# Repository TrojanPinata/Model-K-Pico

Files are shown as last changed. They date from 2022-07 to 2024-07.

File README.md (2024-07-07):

# Model K Pico
This is the repository for a custom 75% keyboard designed to be a fusion of the [Cannonkeys Satisfaction75](https://cannonkeys.com/products/gb-satisfaction-75-keyboard-round-2), [CFTKB Mysterium](https://github.com/coseyfannitutti/mysterium), and [Envious Data Delirium](https://github.com/Envious-Data/Env-KB). I've designed around the ATmega32A and similar AVR controllers, and I really wanted to try working with the RP2040 as it comes fully prepackaged and works with [KMK](https://github.com/KMKfw/kmk_firmware) or  [QMK](https://github.com/qmk/qmk_firmware/tree/develop) (with the develop branch *kinda*). The original things that led me to do this were my desire to have the 75% form factor, exposed PCB, rotary encoder for audio, and I2C OLED display all in the same package. My goal was to combine all of these things together while still keeping it reasonable for a layman to make themself. 

I think it has come out pretty decent minus some cracks in the switchplate (because 1.5mm acrylic is really thin) and a misplaced screw hole. I couldnt find M2 screws short notice either so I ended up drilling out the holes to be larger (which was a mistake and I would not do again). I think it looks good, it sounds good, and most of all it works. The only thing I need is some pads to keep  it from slipping :).

If you plan on making this yourself I will try and make a guide in the future, but that might take a bit. I recommend [Ponoko](https://www.ponoko.com/) for the acrylic and [JLCPCB](https://jlcpcb.com/) for the PCB manufacturing. Everything else can be found in the BOM from either your local hardware store, [Keeb.io](https://keeb.io/) or [Divinikey](https://divinikey.com/). I chose to use some cheap keycaps and Gateron KS-9 2.0 Red switches and I like how everything feels. Anyway, if you have any questions start a issue or something B).

Note 07/07/24: I still daily drive this keyboard and something I think I should mention if you plan to use KMK daily is that the CircuitPython drive will inevitably corrupt. It lasted me a good two years before it started to get weird and then I basically could not mount the drive. It’s not a big deal if it works (and honestly, I only noticed it was bad when I went to reference some code). I switched to QMK recently and it has been so much better. The build I used is based on one of my future projects and works wonders.

final build

top down

rear

pcb but 3d

pcb 3d back

pcb in kicad

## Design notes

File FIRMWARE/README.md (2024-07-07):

# Firmware
~~I used KMK for this project because python is easy. I *plan* to eventually switch over to QMK less for the advanced features and more for the cleanliness of it. I don't think I'll do it soon becuase of the way the RP2040 isn't fully supported. In the meantime, pretty much everything that can be done in QMK can be done in KMK. With exception to turning off the OLED display it seems.~~

Switched to QMK and it is quite literally a equivalent to better experience. I put the keymap and uf2 here incase someone needs to flash their board.

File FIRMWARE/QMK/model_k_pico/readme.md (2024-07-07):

# Model-B

A 75% keyboard based on the RP2040.

* Keyboard Maintainer: [Brian Hill](https://github.com/TrojanPinata)
* Hardware Supported: [GitHub](https://github.com/TrojanPinata/Model-B)

## Revisions

At the current moment there is only one variant of the Model-B, the rev-0 (aka the prototype board). Any others are clones and may not have the exact firmware requirements.

## Building and Flashing

Make example for this keyboard (after setting up your build environment):

    make trojan_pinata/model-b/rev0:default
    
Flashing example for this keyboard:

    make trojan_pinata/model-b/rev0:default:flash

Compile example:

    qmk compile -kb trojan_pinata/model_b/rev0 -km default

See the [build environment setup](https://docs.qmk.fm/#/getting_started_build_tools) and the [make instructions](https://docs.qmk.fm/#/getting_started_make_guide) for more information. Brand new to QMK? Start with our [Complete Newbs Guide](https://docs.qmk.fm/#/newbs).

## Bootloader

Enter the bootloader in 3 ways:

* **Bootmagic reset**: Hold down the top left key and plug in the keyboard. This will also clear the emulated EEPROM, so it is a good first step if the keyboard is misbehaving.
* **Physical reset button**: Hold down the `BOOTSEL` button on the Pi Pico, then either plug the board in or press the `RESET` button.
* **Keycode in layout**: Press the key mapped to `QK_BOOT`. In the pre-supplied keymaps it is on the second layer, replacing the Esc key.

After entering the bootloader through one of the three methods above, the keyboard will appear as a USB mass storage device named `RPI-RP2`. If the CLI is unable to find this device, the compiled `.uf2` file can be manually copied to it. The keyboard will reboot on completion with the new firmware loaded.

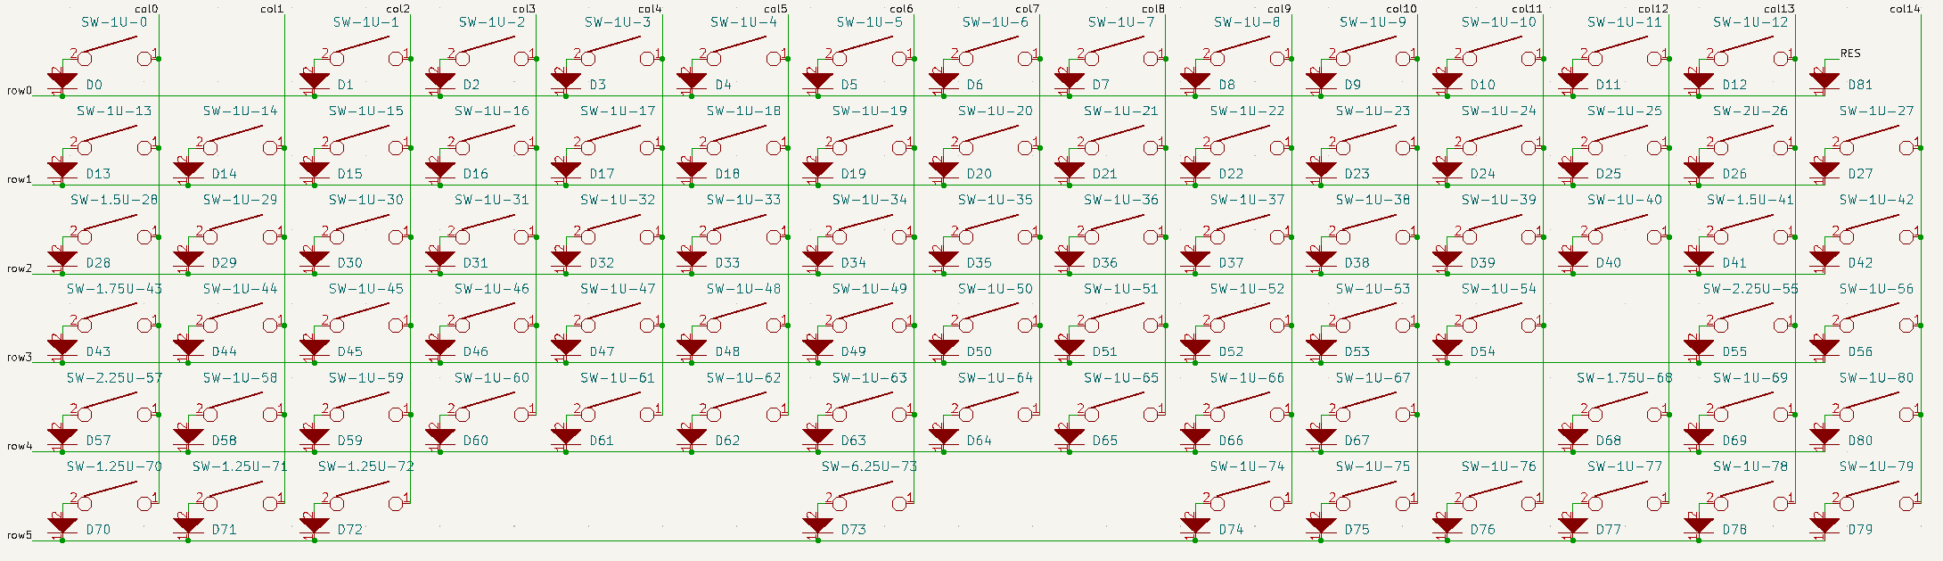
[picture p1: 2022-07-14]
DOCS/IMAGES/Schematic2.png

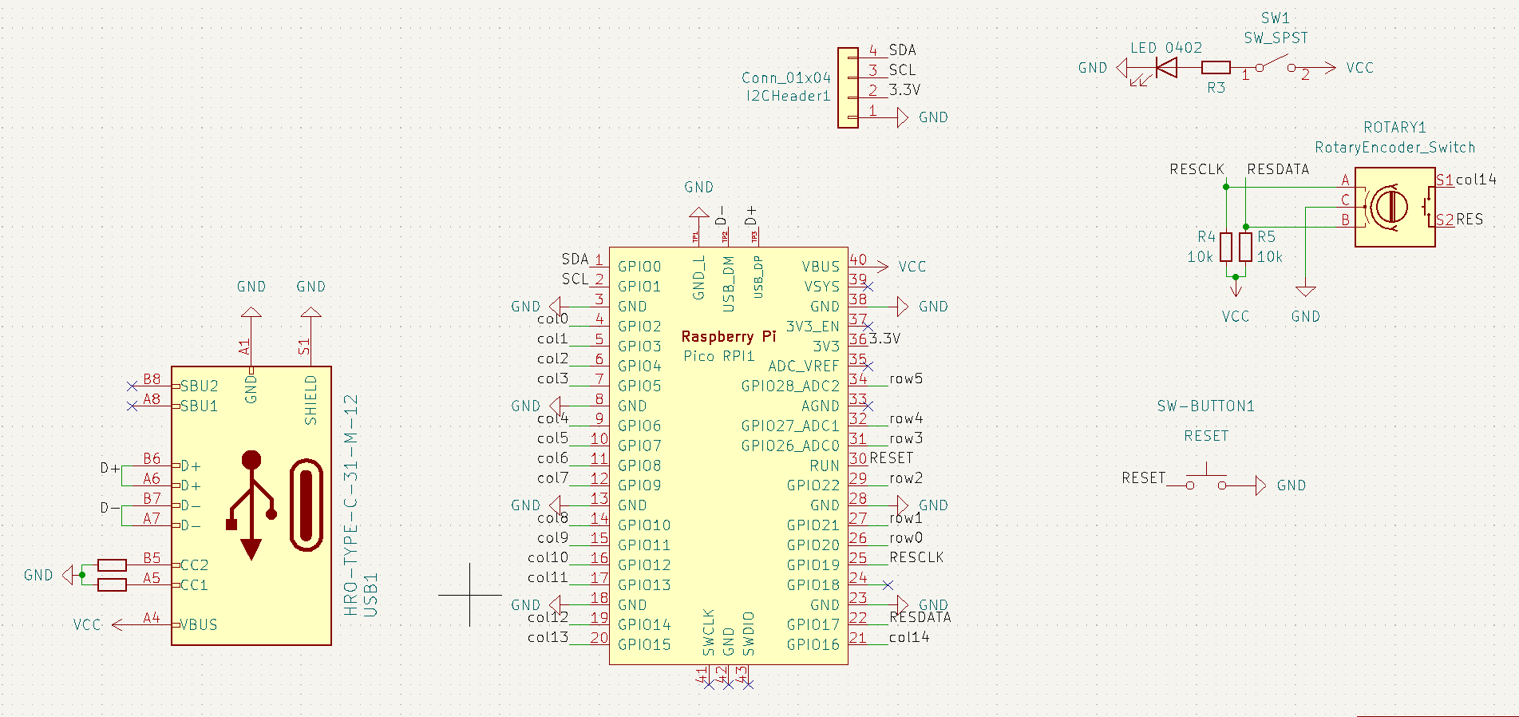
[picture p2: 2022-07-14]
DOCS/IMAGES/Schematic1.png

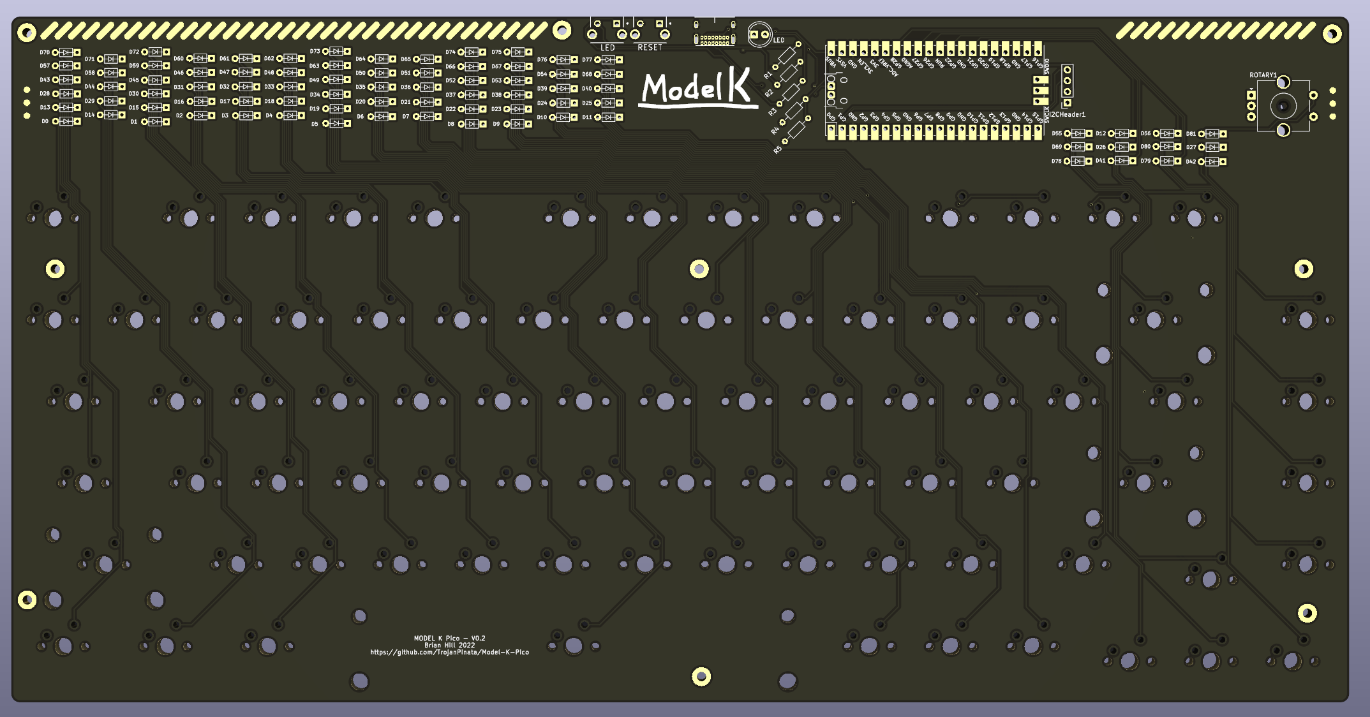
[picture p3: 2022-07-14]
DOCS/IMAGES/PCB2.png

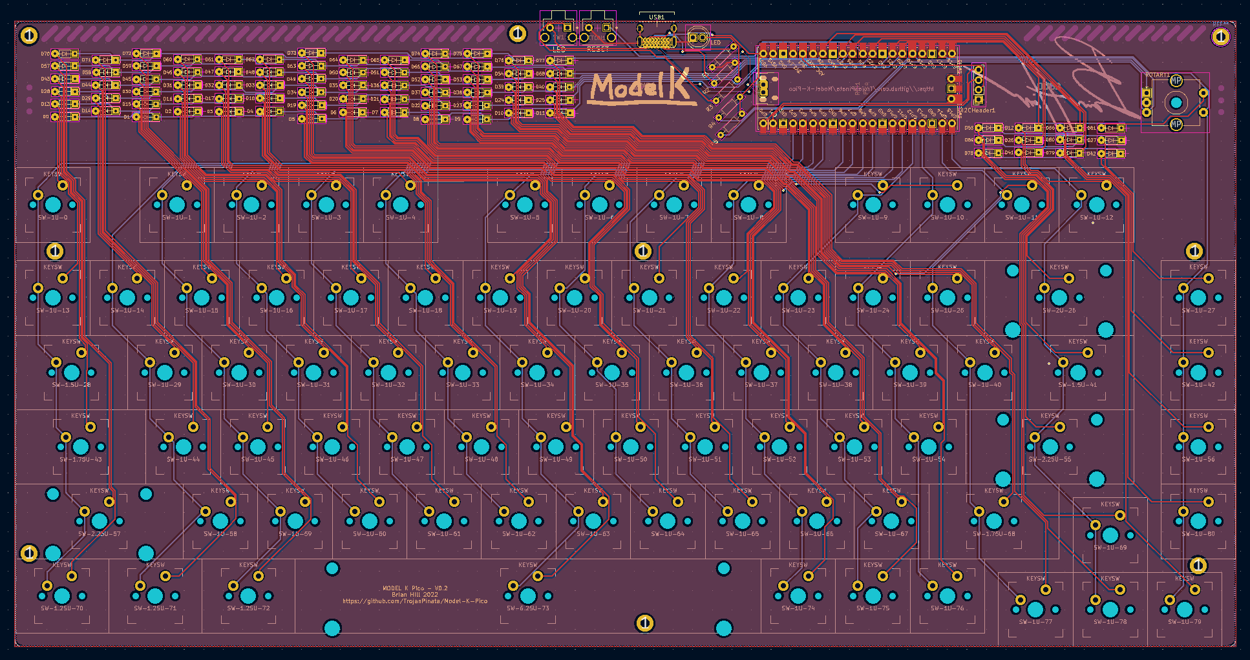
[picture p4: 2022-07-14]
DOCS/IMAGES/PCB1.png

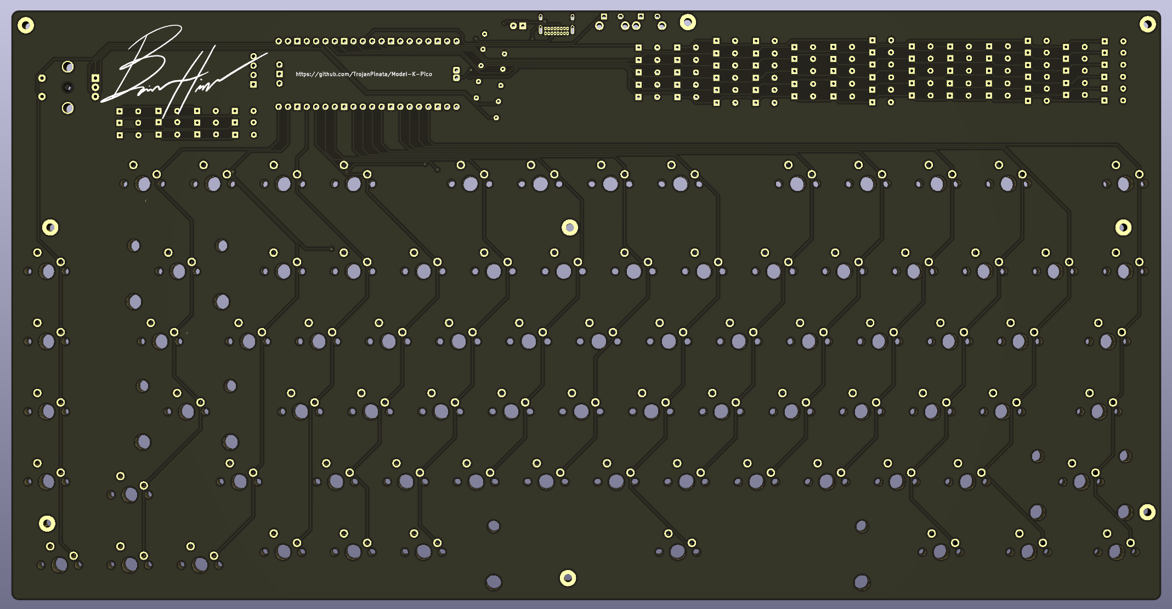
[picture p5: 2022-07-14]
DOCS/IMAGES/PCB3.png

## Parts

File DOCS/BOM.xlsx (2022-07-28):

Item | Description | Count | Notes | Link
Acrylic Switchplate | switchplate | 1
Acrylic Backplate | backplate | 1
Main PCB | pcb | 1
10k Resistor | encoder resistor | 2 | the ebay item to the left is just a general pack for a bunch of different types. they're cheap so you might as well get one so you don't need to order any in the future | https://www.ebay.com/itm/293925230123
5.1k Resistor | USB-C resistor | 2
47k Resistor | LED resistor | 1
SSD1306 | OLED display | 1 | get a second as a backup
EC11 | rotary encoder | 1 | get 2 for peace of mind | https://keeb.io/collections/diy-parts/products/rotary-encoder-ec11
encoder knob | knob for encoder…............... unless for some reason you don't want one i guess | 1 | I like the gmmk pro knob | https://keeb.io/collections/diy-parts/products/rotary-encoder-knob-ec11
1N4148 Diodes | switch diodes | 82 |  | https://keeb.io/collections/diy-parts/products/1n4148-diodes
Omron B3F 3XXX | Horizontal Button | 2 | pretty much anything of similar shape will work. I like the ones from keeb.io | https://www.digikey.com/en/products/detail/omron-electronics-inc-emc-div/B3F-3122/90406
Cherry Style Switches | keyb switches | 81 |  | https://divinikey.com/products/gateron-ks-9-pro-2-0-switches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
Keycaps | keybcaps | 1 | black pcb because color matching to green is hard
M2 Screws 10mm /Nuts | screws/nuts | 18 | 9 screws 18 nuts. I live in the US so #4-40 1/2in also work but you need to drill the holes larger | https://www.homedepot.com/p/Everbilt-M3-0-5-x-10-mm-Phillips-Pan-Head-Zinc-Plated-Machine-Screw-3-Pack-802708/204282658
4x1 Female Header | OLED header | 1 |  | https://www.ebay.com/itm/293487640349
20x1 Female Header | Pico header | 2 |  | https://www.ebay.com/itm/294007298331
USB4085-GF-A | USB-C header | 1 |  | https://www.digikey.com/en/products/detail/gct/USB4085-GF-A/9859662
Raspberry Pi Pico | Microcontroller | 1 |  | https://www.digikey.com/en/products/detail/raspberry-pi/SC0915/13624793
5mm LED | LED | 1 | idk where to buy leds i bought them once like 5 years ago and i still have a ton | https://www.ebay.com/itm/391368927437
2U Stabilizers | PCB mount stabs | 3 |  | https://divinikey.com/collections/keyboard-stabilizers/products/durock-v2-stabilizers-screw-in
6.25U Stabilizer | PCB mount space bar stab | 1
Cable | very nice cable | 1 | not necessary, but you just built a keyboard, so buy yourself something nice | https://www.gloriousgaming.com/products/glorious-coil-cable-crimson-red

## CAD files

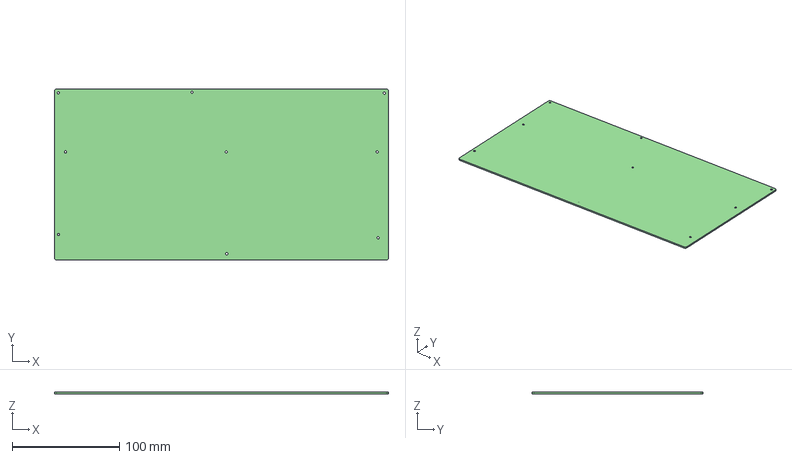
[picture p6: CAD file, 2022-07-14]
ACRYLIC-BOTTOM/ACRYLIC-BOTTOM.step
312.1 x 160.0 x 1.60 mm

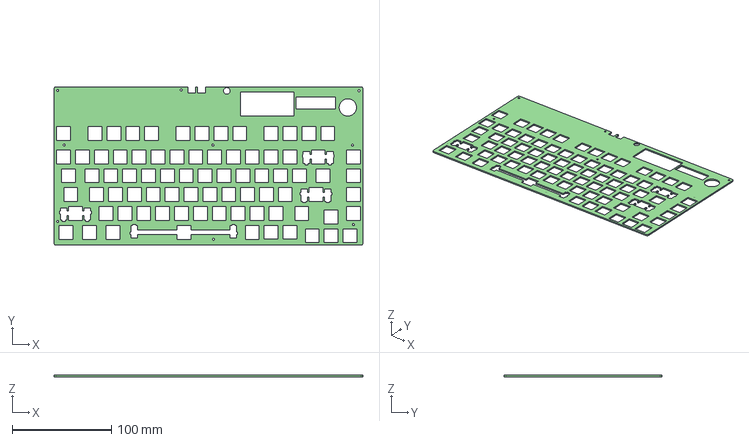
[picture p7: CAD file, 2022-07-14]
ACRYLIC-SP/ACRYLIC-TOP.step
312.1 x 160.0 x 1.60 mm

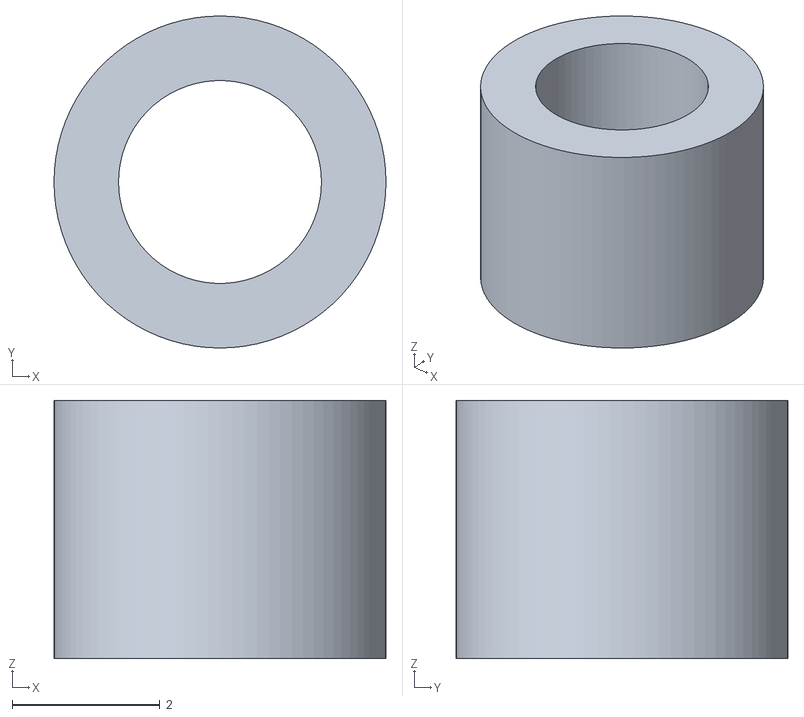
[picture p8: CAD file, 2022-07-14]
DOCS/spacer.stl
4.50 x 4.50 x 3.50

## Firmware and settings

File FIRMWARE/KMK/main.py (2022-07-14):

import board

from kb import KMKKeyboard
from kmk.keys import KC
from kmk.extensions.media_keys import MediaKeys
from kmk.modules.layers import Layers
from kmk.modules.encoder import EncoderHandler
from kmk.extensions.peg_oled_display import Oled,OledDisplayMode,OledReactionType,OledData

keyboard = KMKKeyboard()

keyboard.modules.append(Layers())
layers = Layers()
#media_keys = MediaKeys()
encoder_handler = EncoderHandler()
encoder_handler.pins = ((keyboard.enc_pin0, keyboard.enc_pin1, None, False, 2),)

keyboard.modules = [layers, encoder_handler]

#keyboard.tap_time = 150

#---------------------------------------------------------------------------------------------------
# OLED stuff - only one block should be uncommented at a time
# Uncomment for text
oled_ext = Oled(
    OledData(
        corner_one={0:OledReactionType.LAYER,1:["Model K", "Model K", ""]},
        corner_two={0:OledReactionType.LAYER,1:["Layer 1", "Layer 2", ""]},
        corner_three={0:OledReactionType.LAYER,1:["V0.2", "FW V2.2", ""]},
        corner_four={0:OledReactionType.LAYER,1:["BASE", "ALT", ""]}
        ),
        toDisplay=OledDisplayMode.TXT,flip=False)

# Uncomment for image 
#oled_ext = Oled(OledData(image={0:OledReactionType.LAYER,1:["base.bmp","alt.bmp"]}),toDisplay=OledDisplayMode.IMG,flip=False)

keyboard.extensions.append(oled_ext)

#---------------------------------------------------------------------------------------------------
# Change keymap below for different layouts/differnt layer options
nokey = KC.NO
OLED_TO = KC.TO(0)

keyboard.keymap = [
    [
    # Layer 0
        KC.ESC, nokey, KC.F1, KC.F2, KC.F3, KC.F4, KC.F5, KC.F6, KC.F7, KC.F8, KC.F9, KC.F10, KC.F11, KC.F12, KC.MUTE,
        KC.GRAVE, KC.N1, KC.N2, KC.N3, KC.N4, KC.N5, KC.N6, KC.N7, KC.N8, KC.N9, KC.N0, KC.MINUS, KC.EQUAL, KC.BSPC, KC.DEL,
        KC.TAB, KC.Q, KC.W, KC.E, KC.R, KC.T, KC.Y, KC.U, KC.I, KC.O, KC.P, KC.LBRC, KC.RBRC, KC.BSLS, KC.INS,
        KC.CAPS, KC.A, KC.S, KC.D, KC.F, KC.G, KC.H, KC.J, KC.K, KC.L, KC.SCLN, KC.QUOT, nokey, KC.ENT, KC.HOME,
        KC.LSFT, KC.Z, KC.X, KC.C, KC.V, KC.B, KC.N, KC.M, KC.COMM, KC.DOT, KC.SLSH, nokey, KC.RSHIFT, KC.UP, KC.END,
        KC.LCTL, KC.LGUI, KC.LALT, nokey, nokey, nokey, KC.SPC, nokey, nokey, KC.RALT, KC.MO(1), KC.RCTRL, KC.LEFT, KC.DOWN, KC.RIGHT,
    ],
    [
    # Layer 1
        KC.TRNS, nokey, KC.F13, KC.F14, KC.F15, KC.F16, KC.F17, KC.F18, KC.F19, KC.F20, KC.F21, KC.F22, KC.F23, KC.F24, KC.MUTE,
        KC.TRNS, KC.TRNS, KC.TRNS, KC.TRNS, KC.TRNS, KC.TRNS, KC.TRNS, KC.TRNS, KC.TRNS, KC.TRNS, KC.TRNS, KC.TRNS, KC.TRNS, KC.TRNS, KC.TO(2),
        KC.TRNS, KC.TRNS, KC.TRNS, KC.TRNS, KC.TRNS, KC.TRNS, KC.TRNS, KC.TRNS, KC.TRNS, KC.TRNS, KC.TRNS, KC.TRNS, KC.TRNS, KC.TRNS, KC.TRNS,
        KC.TRNS, KC.TRNS, KC.TRNS, KC.TRNS, KC.TRNS, KC.TRNS, KC.TRNS, KC.TRNS, KC.TRNS, KC.TRNS, KC.TRNS, KC.TRNS, nokey, KC.TRNS, KC.VOLU,
        KC.TRNS, KC.TRNS, KC.TRNS, KC.TRNS, KC.TRNS, KC.TRNS, KC.TRNS, KC.TRNS, KC.TRNS, KC.TRNS, KC.TRNS,  nokey, KC.TRNS, KC.TRNS, KC.VOLD,
        KC.TRNS, KC.TRNS, KC.TRNS, nokey, nokey, nokey, KC.TRNS, nokey, nokey, KC.TRNS, KC.TRNS, KC.TRNS, KC.TRNS, KC.TRNS, KC.TRNS,
    ],
    [
    # Layer 2
    # does this look like hell and work badly? yes it sure does, but it works when I want to sleep without the glow of stupid oled displays next to my face
        OLED_TO, nokey, OLED_TO, OLED_TO, OLED_TO, OLED_TO, OLED_TO, OLED_TO, OLED_TO, OLED_TO, OLED_TO, OLED_TO, OLED_TO, OLED_TO, OLED_TO,
        OLED_TO, OLED_TO, OLED_TO, OLED_TO, OLED_TO, OLED_TO, OLED_TO, OLED_TO, OLED_TO, OLED_TO, OLED_TO, OLED_TO, OLED_TO, OLED_TO, OLED_TO,
        OLED_TO, OLED_TO, OLED_TO, OLED_TO, OLED_TO, OLED_TO, OLED_TO, OLED_TO, OLED_TO, OLED_TO, OLED_TO, OLED_TO, OLED_TO, OLED_TO, OLED_TO,
        OLED_TO, OLED_TO, OLED_TO, OLED_TO, OLED_TO, OLED_TO, OLED_TO, OLED_TO, OLED_TO, OLED_TO, OLED_TO, OLED_TO, nokey, OLED_TO, OLED_TO,
        OLED_TO, OLED_TO, OLED_TO, OLED_TO, OLED_TO, OLED_TO, OLED_TO, OLED_TO, OLED_TO, OLED_TO, OLED_TO, nokey, OLED_TO, OLED_TO, OLED_TO,
        OLED_TO, OLED_TO, OLED_TO, nokey, nokey, nokey, OLED_TO, nokey, nokey, OLED_TO, OLED_TO, OLED_TO, OLED_TO, OLED_TO, OLED_TO,
    ],
]

# Change for desired effect of rotary encoder
encoder_handler.map = [
    ((KC.VOLD, KC.VOLU, KC.NO),),    # Layer 0
    ((KC.TRNS, KC.TRNS, KC.TRNS),),  # Layer 1
    ((KC.TRNS, KC.TRNS, KC.TRNS),),  # Layer 2
    ]

#---------------------------------------------------------------------------------------------------
# dont mess with this please for the love of god its super important like ple
if __name__ == '__main__':
    keyboard.go()

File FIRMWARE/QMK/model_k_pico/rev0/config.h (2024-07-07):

// Copyright 2022 Stefan Kerkmann
// SPDX-License-Identifier: GPL-2.0-or-later

#pragma once


#define DEBUG_MATRIX_SCAN_RATE

//#define QMK_WAITING_TEST_BUSY_PIN GP8
//#define QMK_WAITING_TEST_YIELD_PIN GP9

#define RP2040_BOOTLOADER_DOUBLE_TAP_RESET
#define RP2040_BOOTLOADER_DOUBLE_TAP_RESET_LED GP25
#define RP2040_BOOTLOADER_DOUBLE_TAP_RESET_TIMEOUT 500U

// settings for the oled keyboard demo with Adafruit 0.91" OLED display on the Stemma QT port
#define OLED_DISPLAY_128X32
#define I2C_DRIVER I2CD0
#define I2C1_SDA_PIN GP0
#define I2C1_SCL_PIN GP1

#define OLED_BRIGHTNESS 255 // you can reduce the brightness, but not make it brighter!
#define OLED_TIMEOUT 300000 // 5 minutes before oled turns off

#define ENCODERS_PAD_A { GP17 }
#define ENCODERS_PAD_B { GP19 }

#define ENCODER_RESOLUTION 4

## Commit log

2022-07-09 Initial Update
    [Model K Pico-0.2.kicad_sch]
2022-07-11 kmk and pcb updates
    [Model K Pico-0.2.kicad_sch]
2022-07-12 gerbers wow
    [ACRYLIC-BOTTOM.kicad_pcb, ACRYLIC-BOTTOM.kicad_sch, ACRYLIC-BOTTOM.step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]
2022-07-14 firmware update, finishing the pcb, and more
    firmware updated to hide drive/serial and added a 'off' state for the oled display
    pcb finished up and ready to send out
    switch plate and backplate finished and ready to send out
    images added and readmes updated and ready to go live
    [ACRYLIC-BOTTOM.kicad_pcb, ACRYLIC-BOTTOM.step, ACRYLIC-TOP.kicad_pcb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]
2022-07-14 BOM and spacer file
    3d printable 3.5mm spacer and a list of everything you may need
    [BOM.xlsx, spacer.stl]
2022-07-28 Finished
    some images and the big update to the readme
    [BOM.xlsx]
2022-10-21 removed artifacts until i remember to add my current images
2024-05-17 add license
    I have to add licenses to all of my repos bc people are stealing some of them and selling them (╥﹏╥)
2024-07-07 switched to QMK
